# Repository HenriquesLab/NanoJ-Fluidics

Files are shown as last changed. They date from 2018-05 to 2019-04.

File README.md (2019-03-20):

# NanoJ-Fluidics: open-source fluid exchange in microscopy

Note: visit the [**Wiki**][10] or [**Forum**][12] for latest updates.



NanoJ-Fluidics is an open-source device, composed of easily accessible LEGO-parts, electronics and labware. It is designed to automate and simplify fluid exchange experiments in microscopy. Check the paper in Nature Communications: [Automating multimodal microscopy with
NanoJ-Fluidics][11].

## It consists of three parts:
+ [LEGO-based, multiplexable and compact syringe pumps][4]
+ [A simple "hack" to enable liquid exchange on cell culture dishes][5]
+ And a comprehensive [electronic][6] and [software][7] control suite to control the pumps.

This [Wiki][10] provides all the information necessary for researchers to reproduce their own systems and start performing fluidic experiments on their microscopes.

## Developers
NanoJ-Fluidics is developed in a collaboration between the [Henriques][1] and [Leterrier][9] laboratories. 

## Developers
NanoJ-Fluidics is developed in a collaboration between the [Henriques][1] and [Leterrier][9] laboratories, with contributions from the community:
  * [Matthew Meyer][0mgem0] (La Jolla Institute of Allergy & Immunology's Microscopy Core): 3D printed syringe pump body, v-slot adaptor, other parts (see [section](https://github.com/HenriquesLab/NanoJ-Fluidics/wiki/Pumpy-3D-Printing-MMeyer)).
  * [Leo Saunders][MySaundersleo] (University of Colorado Denver): 3D printed syringe pump body (see [section](https://github.com/HenriquesLab/NanoJ-Fluidics/wiki/Pumpy-3D-Printing-LSaunders)).

  [1]: http://www.ucl.ac.uk/lmcb/users/ricardo-henriques
  [2]: http://www.ucl.ac.uk/lmcb/
  [3]: http://www.ucl.ac.uk/
  [4]: https://github.com/HenriquesLab/NanoJ-Fluidics/wiki/Pumpy-Home
  [5]: https://github.com/HenriquesLab/NanoJ-Fluidics/wiki/Labware-Home
  [6]: https://github.com/HenriquesLab/NanoJ-Fluidics/wiki/Electronics-Home
  [7]: https://github.com/HenriquesLab/NanoJ-Fluidics/wiki/GUI-Home
  [8]: https://github.com/HenriquesLab/NanoJ-Fluidics/wiki/Files/PedroPumpsSample.png
  [9]: http://www.neurocytolab.org/
  [10]: https://github.com/HenriquesLab/NanoJ-Fluidics/wiki
  [11]: https://doi.org/10.1038/s41467-019-09231-9
  [12]: https://gitter.im/NanoJ-Fluidics
  [3DPrint]: Pumpy-3D-Printing
  [0mgem0]: https://twitter.com/0mgem0
  [MySaundersleo]: https://twitter.com/MySaundersleo

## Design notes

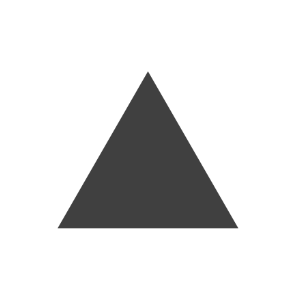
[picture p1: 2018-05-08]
src/nanoj/pumpControl/java/sequentialProtocol/images/up.png

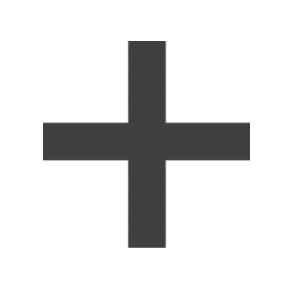
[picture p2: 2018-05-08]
src/nanoj/pumpControl/java/sequentialProtocol/images/duplicate.png

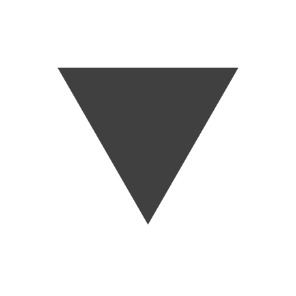
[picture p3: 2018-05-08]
src/nanoj/pumpControl/java/sequentialProtocol/images/down.png

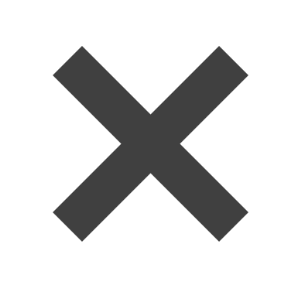
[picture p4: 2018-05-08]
src/nanoj/pumpControl/java/sequentialProtocol/images/expire.png

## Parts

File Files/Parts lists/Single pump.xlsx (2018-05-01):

Name | Picture | Design ID | Quantity
BRICK 2X2 |  | 3003 | 5
BRICK 2X3 |  | 3002 | 1
BRICK 2X4 |  | 3001 | 1
BRICK 2X6 |  | 44237 | 2
BRICK 2X8 |  | 93888 | 1
TECHNIC BRICK 1X6, Ø4,9 |  | 3894 | 5
TECHNIC BRICK 1X10 Ø4.9 |  | 2730 | 4
PLATE 2X3 |  | 3021 | 2
PLATE 2X4 |  | 3020 | 11
PLATE 2X6 |  | 3795 | 3
PLATE 2X16 |  | 4282 | 1
PLATE 8X16 |  | 92438 | 1
BUSH FOR CROSS AXLE |  | 6590 | 7
CROSS AXLE 6M |  | 3706 | 3
CROSS AXLE 8M |  | 3707 | 5
FUNC. MOTOR Ø24X6M |  | 8883-1 | 1 | Not available on Lego Pick a brick
BEAM 1X2 W/CROSS AND HOLE |  | 60483 | 4 | Not available on Lego Pick a brick
CROSS AXLE 12M |  | 3708 | 1 | Not available on Lego Pick a brick
Linear Actuator 10-15 M |  | 61927c01 | 2 | Not available on Lego Pick a brick
GEAR WHEEL T=8, M=1 |  | 3647 | 3 | Not available on Lego Pick a brick
GEAR WHEEL Z24 |  | 3648 | 2 | Not available on Lego Pick a brick
GEAR WHEEL 40T |  | 3649 | 2 | Not available on Lego Pick a brick
 |  |  | 67

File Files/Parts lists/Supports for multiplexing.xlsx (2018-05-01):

Name | Picture | Design ID | Quantity
BRICK 1X2 WITHOUT PIN |  | 3065 | 4
BRICK 2X2 |  | 3003 | 7
TECHNIC BRICK 1X10 Ø4.9 |  | 2730 | 6
 |  |  | 17

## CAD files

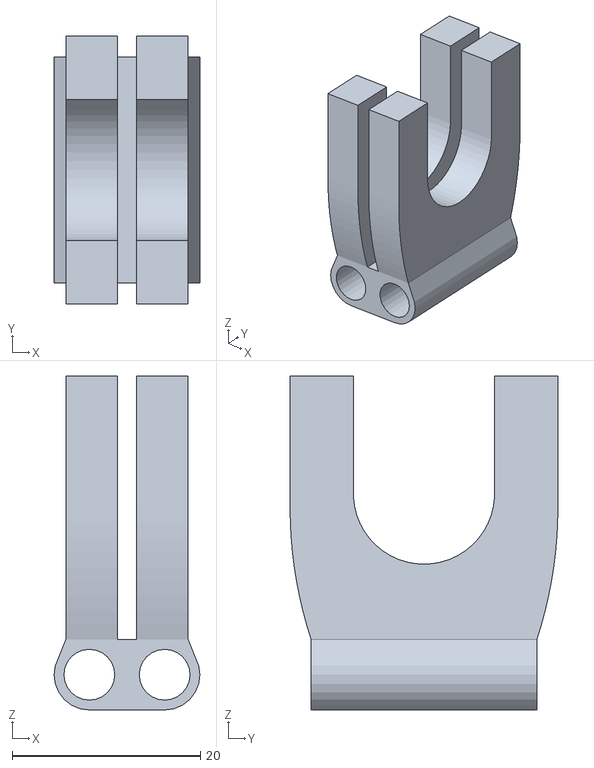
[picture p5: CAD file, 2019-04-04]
Files/3D Printing Parts/MMeyer_Pumpy_BD5ml_2_5.stl
15.5 x 28.5 x 35.5

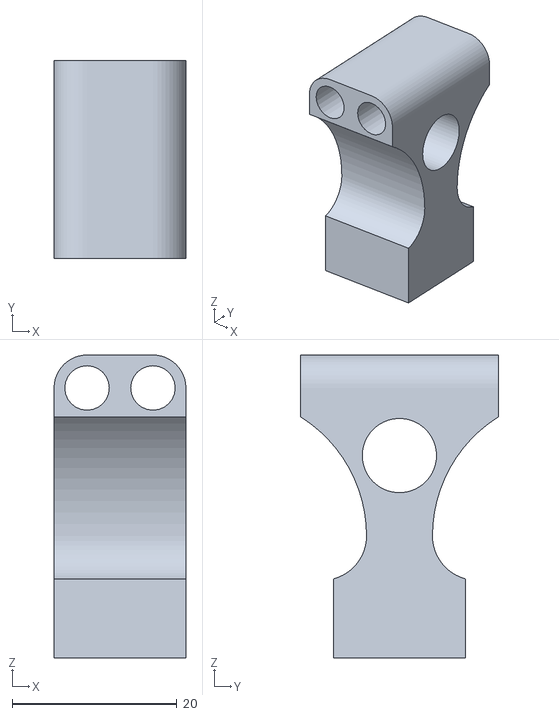
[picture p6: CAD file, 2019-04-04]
Files/3D Printing Parts/MMeyer_Pumpy_LinearActuatorStabilizer_2_5.stl
16.0 x 24.0 x 36.8

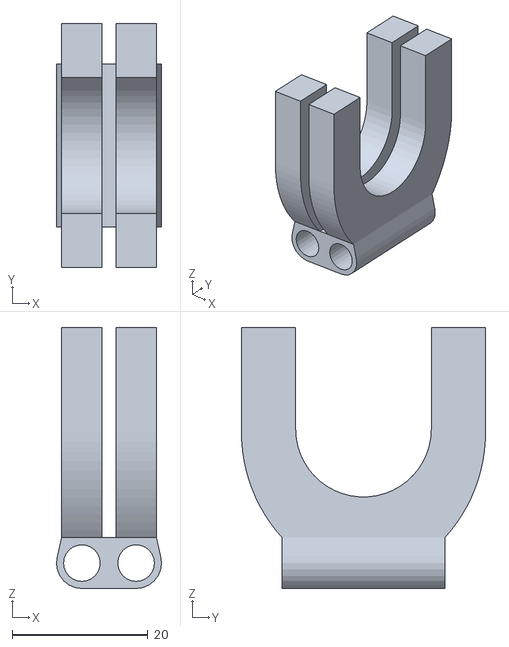
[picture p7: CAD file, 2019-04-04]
Files/3D Printing Parts/MMeyer_Pumpy_BD10ml_2_5.stl
15.5 x 36.0 x 38.5

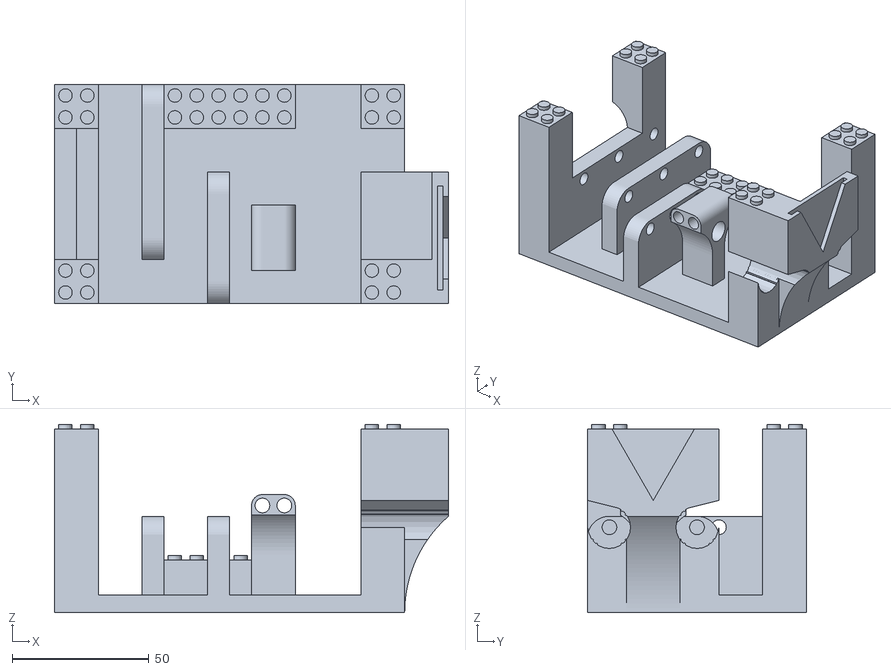
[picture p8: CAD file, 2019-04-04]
Files/3D Printing Parts/MMeyer_SolidPumpy_2_5.stl
144.0 x 80.0 x 68.8

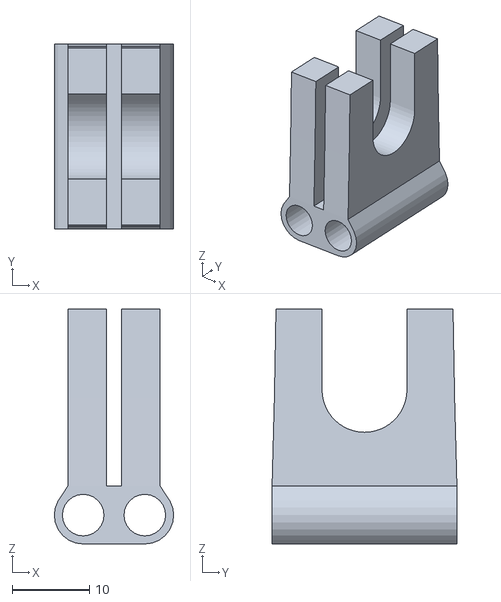
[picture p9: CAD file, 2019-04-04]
Files/3D Printing Parts/MMeyer_Pumpy_BD3ml_2_5.stl
15.5 x 24.0 x 30.5

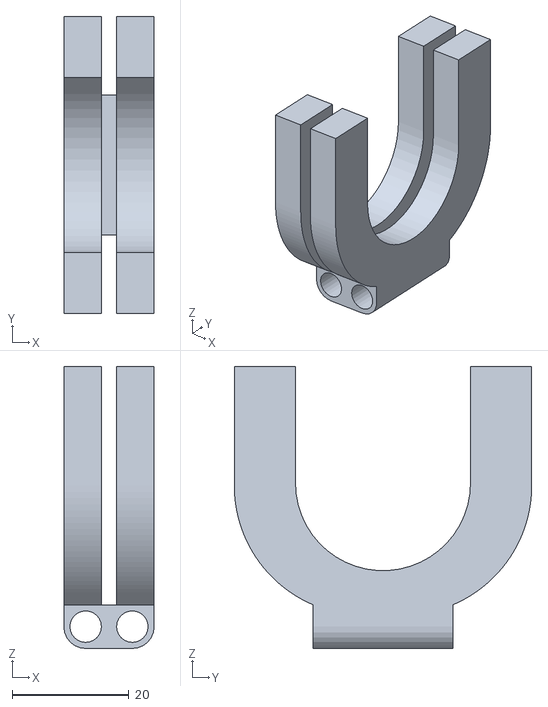
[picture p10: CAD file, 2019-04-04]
Files/3D Printing Parts/MMeyer_Pumpy_BD60ml_2_5.stl
15.5 x 51.0 x 48.3

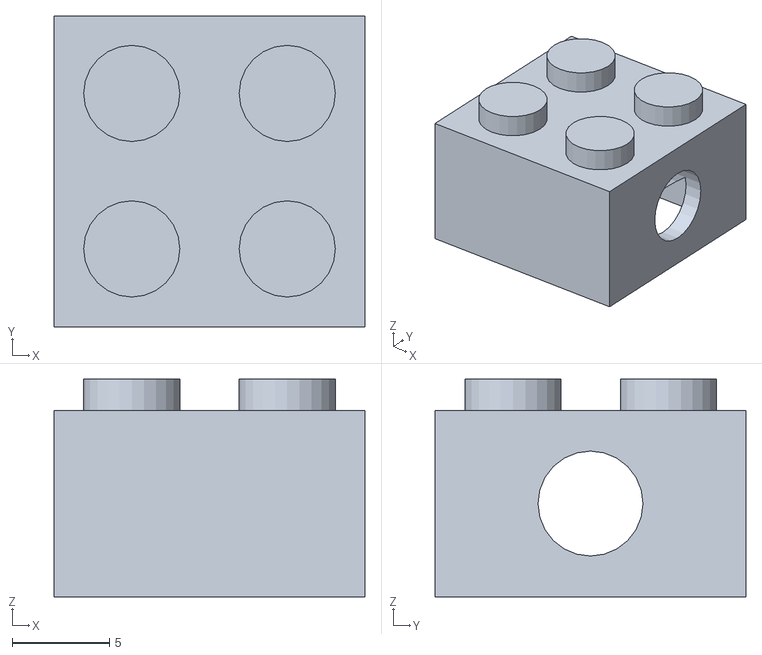
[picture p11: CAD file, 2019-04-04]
Files/3D Printing Parts/MMeyer_Pumpy_PrintingCalibrationBrick_2_5.stl
16.0 x 16.0 x 11.2

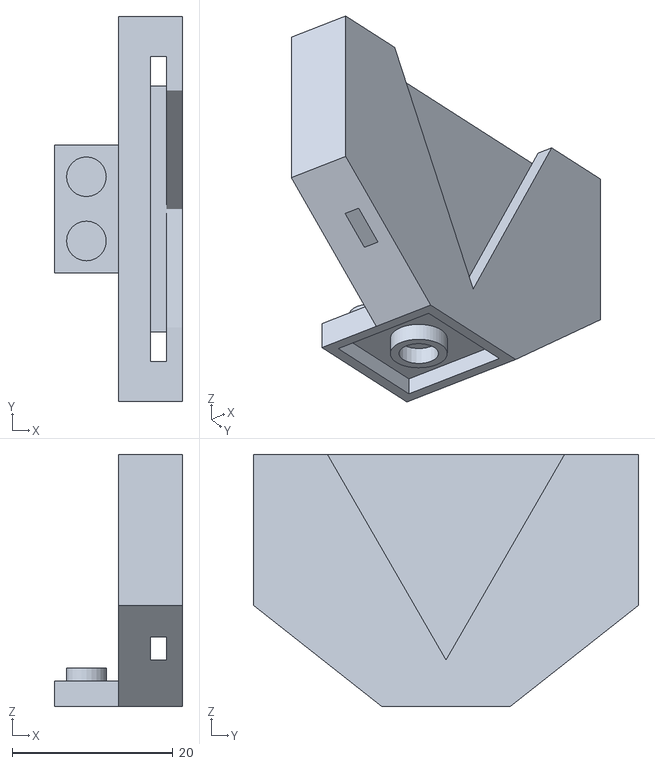
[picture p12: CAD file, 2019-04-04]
Files/3D Printing Parts/MMeyer_Pumpy_VSlot_2_5.stl
16.0 x 48.0 x 31.4

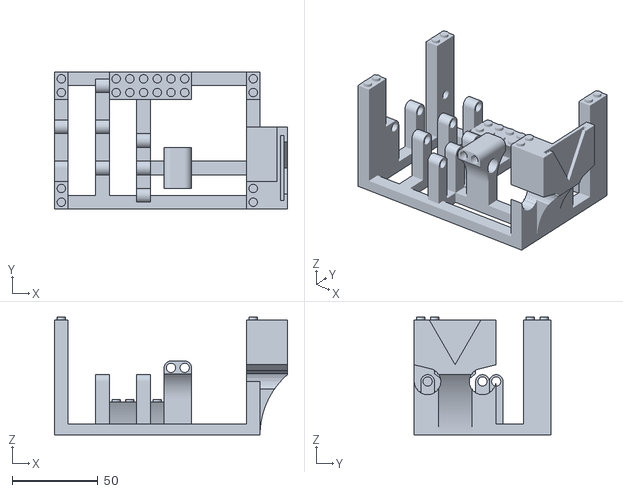
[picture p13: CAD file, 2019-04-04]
Files/3D Printing Parts/MMeyer_SkeletonPumpy_2_5.stl
136.0 x 80.0 x 68.8

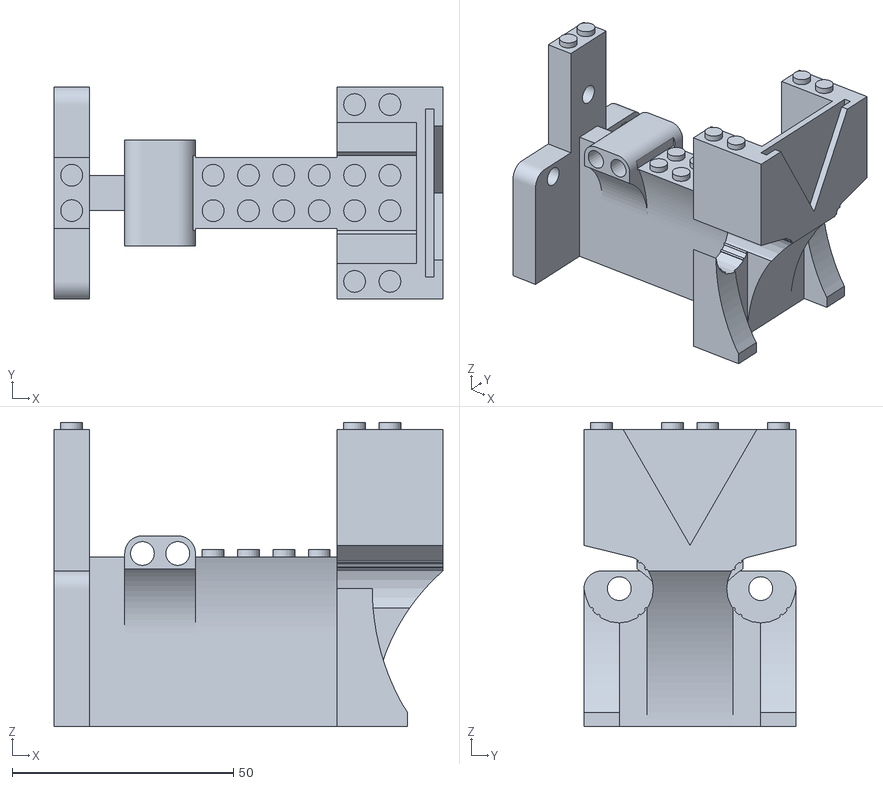
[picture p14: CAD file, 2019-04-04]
Files/3D Printing Parts/MMeyer_PuppyPumpy_2_5.stl
88.0 x 48.0 x 68.8

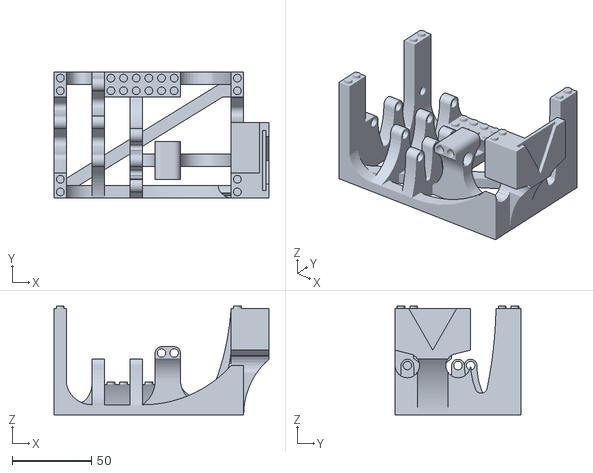
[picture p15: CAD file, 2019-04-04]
Files/3D Printing Parts/MMeyer_DrippyPumpy_2_5.stl
136.0 x 80.0 x 68.8

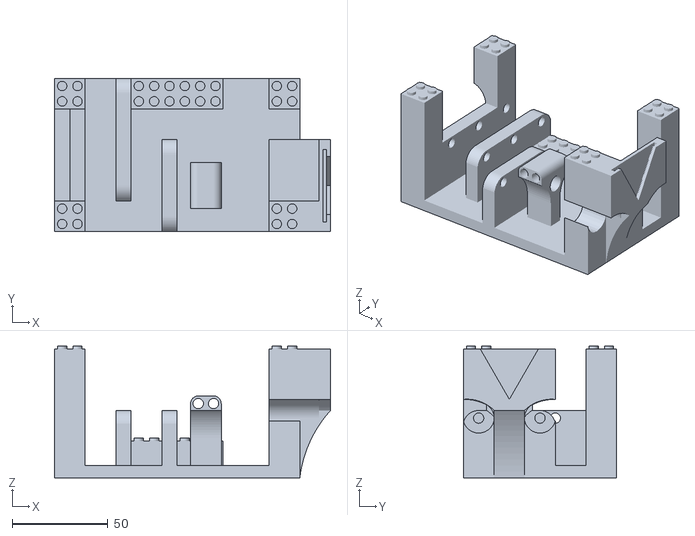
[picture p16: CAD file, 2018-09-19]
Files/3D Printing Parts/MMeyer_Pumpy_2_0.stl
144.0 x 80.0 x 68.8

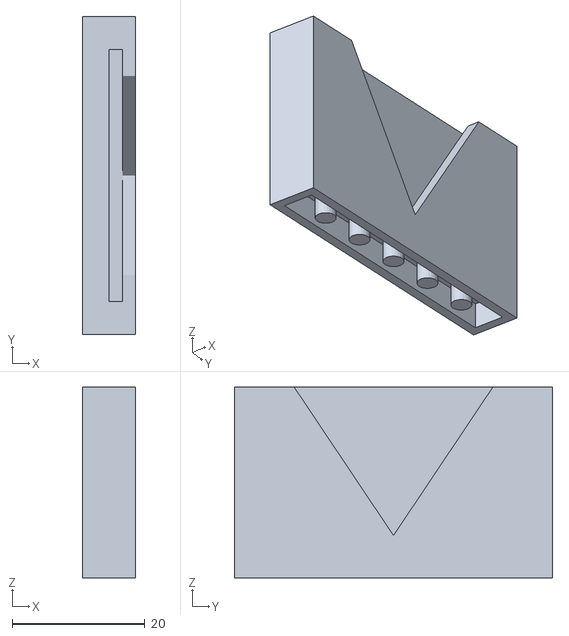
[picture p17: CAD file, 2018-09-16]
Files/3D Printing Parts/MMeyer_VSlotLegoAdaptor_2_0.stl
8.00 x 48.0 x 28.8

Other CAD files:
Files/3D Printing Parts/MMeyer_BD3mlSyringeLinearActuatorAdaptor_2_0.stl
Files/3D Printing Parts/MMeyer_BD5mlSyringeLinearActuatorAdaptor_2_0.stl
Files/3D Printing Parts/MMeyer_BD60mlSyringeLinearActuatorAdaptor_2_0.stl
Files/3D Printing Parts/MMeyer_SkeletonPumpy_2_0.stl
Files/3D Printing Parts/MMeyer_BD10mlSyringeLinearActuatorAdaptor_2_0.stl
Files/3D Printing Parts/LSaunders_ActuatorClamp_1_0.stl
Files/3D Printing Parts/LSaunders_Platform_1_0.stl
Files/3D Printing Parts/LSaunders_SyringeClamp_1_0.stl
Files/3D Printing Parts/MMeyer_Pumpy_1_0.stl
Files/3D Printing Parts/MMeyer_Pumpy_1_1beta.stl
Files/3D Printing Parts/MMeyer_ReplacementForLegoPartsMinosLinearActuator_1_1beta.stl
Files/3D Printing Parts/MMeyer_VSlotLegoAdaptor_1_1beta.stl

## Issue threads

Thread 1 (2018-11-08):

Lack of Lego Pump control in version 1.2.3

MattH688, 2018-11-08:
Hello,

As of version 1.2.3 a commit has been submitted with a complied ".jar" which fails to communicate with the Lego pumps but appears to send commands to the Arduino. I am currently unsure if the issue results from version 1.2.2 as there was no complied ".jar" on that release. So far I have been using the last known working release version 1.2.1.

Many thanks,
MattH688

palmada, 2018-11-09:
Hi @MattH688,

Did you just use the JAR? Or the packaged binaries in https://github.com/HenriquesLab/NanoJ-Fluidics/tree/master/PackagedBinaries?

Kind regards,
Pedro

MattH688, 2018-11-09:
Hi @palmada,

I downloaded the entire project "Manual, source-code and binaries for the NanoJ-Fluidics project". I attempted the ".jar" and have attempted to recompile v1.2.3 this morning. I would like to update my original issue as I have realised direct Lego pump control works* but sequence does not appear to send commands to the correct pump. I have checked and confirmed the messages to the Arduino are correct. I believe it is an issue somewhere with the sequence java files assigning the correct pump index.

Many thanks,
Matthew

*As expected except for failing to stop after the sequence and the hard coded max speed for Lego pumps which I have fixed in my fork. Happy to pull into yours but ideally need sequences fixed first on your master.

palmada, 2018-12-06:
Hi @MattH688 do you still have an issue with the latest release?

MattH688, 2018-12-13:
@palmada Working perfectly now, thanks!

Sorry for the delay, had my viva and other on going work 📃 Happy holidays 👍

Closed 2018-12-13.

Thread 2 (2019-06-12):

Withdraw time acting as pump time

espruston, 2019-06-12:
When designing a sequential protocol the value included for the withdraw time seems to become the amount of time that the pump runs for rather than the time calculated by volume/syringe type. This happens for every pump for every step except for the last step in the protocol, which seems to calculate pump run time as intended. This issue also occurs regardless of whether the "Withdraw between steps?" or "Wd" box is checked next to the step. I'm running on MM 1.4, Windows 10 with an Arduino Uno. Direct pump control works fine.

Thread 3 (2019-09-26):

MM_plugin error

kforti, 2019-09-26:
Hello,
I am getting an error when I try to use NanoJ-Fluidics as a micromanager plugin.

Here are the errors:

`2019-09-26T11:17:20.536925 tid139896359667456 [IFO,App] Plugin command: NanoJ-Fluidics
2019-09-26T11:17:20.537400 tid139896359667456 [IFO,App] Thread 19 (AWT-EventQueue-0) terminated with uncaught exception
2019-09-26T11:17:20.537447 tid139896359667456 [IFO,App] java.lang.NoClassDefFoundError: Could not initialize class nanoj.pumpControl.java.sequentialProtocol.GUI
2019-09-26T11:17:20.537575 tid139896359667456 [IFO,App]   at nanoj.pumpControl.java.sequentialProtocol.MicroManagerPlugin.<init>(MicroManagerPlugin.java:18)
2019-09-26T11:17:20.537586 tid139896359667456 [IFO,App]   at java.base/jdk.internal.reflect.NativeConstructorAccessorImpl.newInstance0(Native Method)
2019-09-26T11:17:20.537598 tid139896359667456 [IFO,App]   at java.base/jdk.internal.reflect.NativeConstructorAccessorImpl.newInstance(NativeConstructorAccessorImpl.java:62)
2019-09-26T11:17:20.537609 tid139896359667456 [IFO,App]   at java.base/jdk.internal.reflect.DelegatingConstructorAccessorImpl.newInstance(DelegatingConstructorAccessorImpl.java:45)
2019-09-26T11:17:20.537620 tid139896359667456 [IFO,App]   at java.base/java.lang.reflect.Constructor.newInstance(Constructor.java:490)
2019-09-26T11:17:20.537632 tid139896359667456 [IFO,App]   at java.base/java.lang.Class.newInstance(Class.java:584)
2019-09-26T11:17:20.537643 tid139896359667456 [IFO,App]   at org.micromanager.pluginmanagement.PluginItem.instantiate(PluginItem.java:89)
2019-09-26T11:17:20.537654 tid139896359667456 [IFO,App]   at org.micromanager.pluginmanagement.PluginManager.displayPlugin(PluginManager.java:110)
2019-09-26T11:17:20.537666 tid139896359667456 [IFO,App]   at org.micromanager.pluginmanagement.PluginManager.access$100(PluginManager.java:22)
2019-09-26T11:17:20.537677 tid139896359667456 [IFO,App]   at org.micromanager.pluginmanagement.PluginManager$2.run(PluginManager.java:64)
2019-09-26T11:17:20.537688 tid139896359667456 [IFO,App]   at org.micromanager.utils.GUIUtils$3.actionPerformed(GUIUtils.java:361)
2019-09-26T11:17:20.537700 tid139896359667456 [IFO,App]   at java.desktop/javax.swing.AbstractButton.fireActionPerformed(AbstractButton.java:1967)
2019-09-26T11:17:20.537711 tid139896359667456 [IFO,App]   at java.desktop/javax.swing.AbstractButton$Handler.actionPerformed(AbstractButton.java:2308)
2019-09-26T11:17:20.537722 tid139896359667456 [IFO,App]   at java.desktop/javax.swing.DefaultButtonModel.fireActionPerformed(DefaultButtonModel.java:405)
2019-09-26T11:17:20.537734 tid139896359667456 [IFO,App]   at java.desktop/javax.swing.DefaultButtonModel.setPressed(DefaultButtonModel.java:262)
2019-09-26T11:17:20.537745 tid139896359667456 [IFO,App]   at java.desktop/javax.swing.AbstractButton.doClick(AbstractButton.java:369)
2019-09-26T11:17:20.537756 tid139896359667456 [IFO,App]   at java.desktop/javax.swing.plaf.basic.BasicMenuItemUI.doClick(BasicMenuItemUI.java:1020)
2019-09-26T11:17:20.537768 tid139896359667456 [IFO,App]   at java.desktop/javax.swing.plaf.basic.BasicMenuItemUI$Handler.mouseReleased(BasicMenuItemUI.java:1064)
2019-09-26T11:17:20.537779 tid139896359667456 [IFO,App]   at java.desktop/java.awt.AWTEventMulticaster.mouseReleased(AWTEventMulticaster.java:297)
2019-09-26T11:17:20.537790 tid139896359667456 [IFO,App]   at java.desktop/java.awt.Component.processMouseEvent(Component.java:6632)
2019-09-26T11:17:20.537802 tid139896359667456 [IFO,App]   at java.desktop/javax.swing.JComponent.processMouseEvent(JComponent.java:3342)
2019-09-26T11:17:20.537813 tid139896359667456 [IFO,App]   at java.desktop/java.awt.Component.processEvent(Component.java:6397)
2019-09-26T11:17:20.537824 tid139896359667456 [IFO,App]   at java.desktop/java.awt.Container.processEvent(Container.java:2263)
2019-09-26T11:17:20.537836 tid139896359667456 [IFO,App]   at java.desktop/java.awt.Component.dispatchEventImpl(Component.java:5008)
2019-09-26T11:17:20.537847 tid139896359667456 [IFO,App]   at java.desktop/java.awt.Container.dispatchEventImpl(Container.java:2321)
2019-09-26T11:17:20.537858 tid139896359667456 [IFO,App]   at java.desktop/java.awt.Component.dispatchEvent(Component.java:4840)
2019-09-26T11:17:20.537870 tid139896359667456 [IFO,App]   at java.desktop/java.awt.LightweightDispatcher.retargetMouseEvent(Container.java:4918)
2019-09-26T11:17:20.537881 tid139896359667456 [IFO,App]   at java.desktop/java.awt.LightweightDispatcher.processMouseEvent(Container.java:4547)
2019-09-26T11:17:20.537892 tid139896359667456 [IFO,App]   at java.desktop/java.awt.LightweightDispatcher.dispatchEvent(Container.java:4488)
2019-09-26T11:17:20.537904 tid139896359667456 [IFO,App]   at java.desktop/java.awt.Container.dispatchEventImpl(Container.java:2307)
2019-09-26T11:17:20.537915 tid139896359667456 [IFO,App]   at java.desktop/java.awt.Window.dispatchEventImpl(Window.java:2772)
2019-09-26T11:17:20.537926 tid139896359667456 [IFO,App]   at java.desktop/java.awt.Component.dispatchEvent(Component.java:4840)
2019-09-26T11:17:20.537938 tid139896359667456 [IFO,App]   at java.desktop/java.awt.EventQueue.dispatchEventImpl(EventQueue.java:772)
2019-09-26T11:17:20.537949 tid139896359667456 [IFO,App]   at java.desktop/java.awt.EventQueue$4.run(EventQueue.java:721)
2019-09-26T11:17:20.537960 tid139896359667456 [IFO,App]   at java.desktop/java.awt.EventQueue$4.run(EventQueue.java:715)
2019-09-26T11:17:20.537972 tid139896359667456 [IFO,App]   at java.base/java.security.AccessController.doPrivileged(Native Method)
2019-09-26T11:17:20.537983 tid139896359667456 [IFO,App]   at java.base/java.security.ProtectionDomain$JavaSecurityAccessImpl.doIntersectionPrivilege(ProtectionDomain.java:85)
2019-09-26T11:17:20.537994 tid139896359667456 [IFO,App]   at java.base/java.security.ProtectionDomain$JavaSecurityAccessImpl.doIntersectionPrivilege(ProtectionDomain.java:95)
2019-09-26T11:17:20.538006 tid139896359667456 [IFO,App]   at java.desktop/java.awt.EventQueue$5.run(EventQueue.java:745)
2019-09-26T11:17:20.538017 tid139896359667456 [IFO,App]   at java.desktop/java.awt.EventQueue$5.run(EventQueue.java:743)
2019-09-26T11:17:20.538029 tid139896359667456 [IFO,App]   at java.base/java.security.AccessController.doPrivileged(Native Method)
2019-09-26T11:17:20.538040 tid139896359667456 [IFO,App]   at java.base/java.security.ProtectionDomain$JavaSecurityAccessImpl.doIntersectionPrivilege(ProtectionDomain.java:85)
2019-09-26T11:17:20.538051 tid139896359667456 [IFO,App]   at java.desktop/java.awt.EventQueue.dispatchEvent(EventQueue.java:742)
2019-09-26T11:17:20.538063 tid139896359667456 [IFO,App]   at java.desktop/java.awt.EventDispatchThread.pumpOneEventForFilters(EventDispatchThread.java:203)
2019-09-26T11:17:20.538074 tid139896359667456 [IFO,App]   at java.desktop/java.awt.EventDispatchThread.pumpEventsForFilter(EventDispatchThread.java:124)
2019-09-26T11:17:20.538085 tid139896359667456 [IFO,App]   at java.desktop/java.awt.EventDispatchThread.pumpEventsForHierarchy(EventDispatchThread.java:113)
2019-09-26T11:17:20.538097 tid139896359667456 [IFO,App]   at java.desktop/java.awt.EventDispatchThread.pumpEvents(EventDispatchThread.java:109)
2019-09-26T11:17:20.538108 tid139896359667456 [IFO,App]   at java.desktop/java.awt.EventDispatchThread.pumpEvents(EventDispatchThread.java:101)
2019-09-26T11:17:20.538119 tid139896359667456 [IFO,App]   at java.desktop/java.awt.EventDispatchThread.run(EventDispatchThread.java:90)
`

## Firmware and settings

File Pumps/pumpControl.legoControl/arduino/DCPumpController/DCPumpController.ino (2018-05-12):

/* 

This is the firmware for an Arduino Uno to drive DC motor pumps through
the Adafruit Motor Shield v2, while under control of our MicroManager
plugins.

© Pedro Almada, UCL, 2015

Commands:
g = get status of all pumps
a = stop all pumps
p = get number of pumps
axy = stop pump xy
sxynnn = for pump xy set speed nnn
rxydttttt - Start pump xy in direction d for ttttt seconds

The commands use this notation:
d = 1 is forward, d = 2 is backwards
x = shield address {1-nShields}
y = motor/pump address {1-nMotorsPerShield}
nnn = speed {000-255}
ttttt = duration {00001-99999}

Our testing with 1 ml syringe tells us the speed will correspond to:
255 - 2.3 microliters/second

*/

//// Imports
#include <EEPROM.h>
// Adafruit Motor Shield libraries
#include <Wire.h>
#include <Adafruit_MotorShield.h>

//// Settings

// Number of shields (MAX: 9)
const int nShields = 4;
// Number of DC motors per shield (MAX on Adafruit Motor Shield v2: 4)
const int nMotorsPerShield = 4;
// Character which signals end of message from PC
char endMessage = '.';

// Misc. initializations
byte currentShield;
byte currentMotor;
int eeAddress = 0;
const int maxMessageLength = 9;
unsigned long startTime = 0;
unsigned long elapsedTime = 0;
unsigned long targetTime = 0;
boolean timeCounter = false;
Adafruit_MotorShield afms[nShields];
Adafruit_DCMotor *motor[nShields][nMotorsPerShield];

// The Arduino should keep track of what the motors have been told to do. 
// We can address each motor's status by accessing the values on motorStatus
// Format is: [shield][motor][speed/state]
// Speed can vary from 0 to 255
// States are: 0 - stop; 1 - forward; 2 - backward.
int motorStatus[nShields][nMotorsPerShield][2] = {{}};

void setup() {
  // Start serial communication and set baud-rate
  Serial.begin(57600);
  Serial.println("Connected!");

  // We now create a Motor Shield object for each shield. Their address 
  // (96-128) is set by soldering a few jumpers.
  // see: https://learn.adafruit.com/adafruit-motor-shield-v2-for-arduino/stacking-shields
  // Note here I'm using decimal values for the address which is simpler
  // but their tutorial uses hex.
  
  unsigned char address = 96;

  // Create array of shield objects
  
  for (int i=0; i<nShields; i++) {
    afms[i] = Adafruit_MotorShield(address);
    address = ++address;
    // Initialize shield objects with the default frequency 1.6KHz
    afms[i].begin();
  }

  // For each shield we then get each of the their motors.
  EEPROM.get(eeAddress, motorStatus);
  for (int i=0; i<nShields; i++) {
    for (int j=0; j<nMotorsPerShield; j++) {
      motor[i][j] = afms[i].getMotor(j+1);
      motor[i][j]->setSpeed(motorStatus[i][j][0]);
    }
  }
}

void loop() {
  char incoming[maxMessageLength];
  
  // If a pump has been started, we stop all pumps after a targetTime amount of time
  if (timeCounter == true) {
    elapsedTime = millis() - startTime;
    if (elapsedTime >= targetTime) {
      for (int i=0; i < nShields; i++) {
           for (int j=0; j < nMotorsPerShield; j++) {
             motorStatus[i][j][1] = 0;
             EEPROM.put(eeAddress, motorStatus);
             motor[i][j]->run(RELEASE);
           }
       }
       elapsedTime = 0;
       targetTime = 0;
       timeCounter = false;
    }
  }
  // If there is a message from the serial port
  if (Serial.available() > 0) {
     
     // Read buffer until end character is reached or maxMessageLength characters are read.
     int lengthOfMessage = Serial.readBytesUntil(endMessage,incoming,maxMessageLength);
     
     // The incoming message will be char array and we're using element 0
     // to determine what is the action to be performed by the pump.
     // The next characters will determine optional parameters such as
     // what pump to start, what speed to set, etc...
     
     // If incoming message is:
     // g = get status of all pumps
     if (incoming[0] == 'g') {
       for (int i=0; i < nShields; i++) {
         for (int j=0; j < nMotorsPerShield; j++) {
           Serial.print("S");
           Serial.print(i + 1);
           Serial.print("M");
           Serial.print(j + 1);
           Serial.print(":");
           Serial.print(motorStatus[i][j][0]);
           Serial.print(",");
           Serial.print(motorStatus[i][j][1]);
           Serial.print(";");
         }
       }
     Serial.println();
     }
     
     // a = stop all pumps
     else if (incoming[0] == 'a' && lengthOfMessage == 1) {
       for (int i=0; i < nShields; i++) {
         for (int j=0; j < nMotorsPerShield; j++) {
           motorStatus[i][j][0] = 255;
           motorStatus[i][j][1] = 0;
           EEPROM.put(eeAddress, motorStatus);
           motor[i][j]->run(RELEASE);
         }
       }
       elapsedTime = 0;
       timeCounter = false;
       Serial.print("Stopped all pumps!");
       Serial.println();
     }
     
     // axy = stop pump xy
     else if (incoming[0] == 'a' && lengthOfMessage != 1) {
       currentShield = incoming[1] - '0' - 1;
       currentMotor  = incoming[2] - '0' - 1;
       motorStatus[currentShield][currentMotor][1] = 0;
       EEPROM.put(eeAddress, motorStatus);
       motor[currentShield][currentMotor]->run(RELEASE);

       elapsedTime = 0;
       timeCounter = false;
       Serial.print("Stopped pump: ");
       Serial.print(incoming[1]);
       Serial.print(",");
       Serial.print(incoming[2]);
       Serial.print("!");
       Serial.println();
     }
     
     //p = get number of pumps
     else if (incoming[0] == 'p') {
      String s = String(nShields, DEC);
      String m = String(nMotorsPerShield, DEC);
      String result = String(s + "." + m);
      Serial.print(result);
      Serial.println();
     }
     
     // sxynnn = for pump xy set speed nnn
     else if (incoming[0] == 's') {
       currentShield = incoming[1] - '0' - 1;
       currentMotor  = incoming[2] - '0' - 1;
       byte a = incoming[3] - '0';
       byte b = incoming[4] - '0';
       byte c = incoming[5] - '0';
       byte currentSpeed = (a*100)+(b*10)+c;
       
       motorStatus[currentShield][currentMotor][0] = currentSpeed;
       EEPROM.put(eeAddress, motorStatus);
       motor[currentShield][currentMotor]->setSpeed(currentSpeed);
       
       Serial.print("Set speed of pump: ");
       Serial.print(incoming[1]);
       Serial.print(",");
       Serial.print(incoming[2]);
       Serial.print(" to ");
       Serial.print(currentSpeed);
       Serial.println();
     }
     
     // rxydttttt - Start pump xy in direction d for ttttt seconds
     // d = 1 is forward, d = 2 is backwards
     else if (incoming[0] == 'r' && lengthOfMessage == maxMessageLength) {
       char targetTimeInput[5] = {incoming[4],incoming[5],incoming[6],incoming[7],incoming[8]};
       targetTime = atol(targetTimeInput)*1000;
       currentShield = incoming[1] - '0' - 1;
       currentMotor  = incoming[2] - '0' - 1;
       motorStatus[currentShield][currentMotor][1] = incoming[3] - '0';
       EEPROM.put(eeAddress, motorStatus);
       
       if (incoming[3] == '1') {
         motor[currentShield][currentMotor]->run(FORWARD);
         startTime = millis();
         elapsedTime = 0;
         timeCounter = true;
         Serial.print("Started pump: ");
         Serial.print(incoming[1]);
         Serial.print(",");
         Serial.print(incoming[2]);
         Serial.print(" in the forward direction.");
         Serial.println();
       }
       else if (incoming[3] == '2') {
         startTime = millis();
         elapsedTime = 0;
         timeCounter = true;
         motor[currentShield][currentMotor]->run(BACKWARD);
         Serial.print("Started pump: ");
         Serial.print(incoming[1]);
         Serial.print(",");
         Serial.print(incoming[2]);
         Serial.print(" in the backward direction.");
         Serial.println();
       };
     }
     
     else {
        Serial.println();
     }
  }
}

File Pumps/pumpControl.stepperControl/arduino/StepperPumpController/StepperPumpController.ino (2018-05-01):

/* 

This is the firmware for an Arduino Uno to drive DC motor pumps through
the Adafruit Motor Shield v2, while under control of our MicroManager
plugins.

© Pedro Almada, UCL, 2015

Commands:
g = get status
a = stop pump
snnn = for pump xy set speed nnn
rdtttttttt - Start pump xy in direction d for ttttttt steps

The commands use this notation:
d = 1 is forward, d = 2 is backwards
nnn = speed {000-maximumSpeed}
ttttttt = steps {0000001-9999999}



*/

//// Imports
#include <EEPROM.h>
// Adafruit Motor Shield libraries
#include <Wire.h>
#include <Adafruit_MotorShield.h>
#include <AccelStepper.h>
#include "utility/Adafruit_PWMServoDriver.h"


// How many steps can the motor take per full revolution?
const uint16_t resolution = 3200;
const uint16_t maximumSpeed = 400;


// Character which signals end of message from PC
char endMessage = '.';

// Misc. initializations
int eeAddress = 0;
int motorStatus = 0;
const uint32_t acceleration = resolution*resolution;
const int maxMessageLength = 9;
Adafruit_MotorShield shield = Adafruit_MotorShield();
Adafruit_StepperMotor *motor = shield.getStepper(resolution, 1);

void forward() {  
  motor->onestep(FORWARD, MICROSTEP);
}
void backward() {  
  motor->onestep(BACKWARD, MICROSTEP);
}

AccelStepper stepper(forward, backward);

void setup() {
  // Start serial communication and set baud-rate
  Serial.begin(57600);
  Serial.println("Connected!");

  shield.begin();

  stepper.setMaxSpeed(resolution);
  stepper.setAcceleration(acceleration);
  
  motor->release();
}

void loop() {
  stepper.run();
  char incoming[maxMessageLength];

  // If there is a message from the serial port
  if (Serial.available() > 0) {
     stepper.run();
     
     // Read buffer until end character is reached or maxMessageLength characters are read.
     int lengthOfMessage = Serial.readBytesUntil(endMessage,incoming,maxMessageLength);
     
     stepper.run();
     
     // The incoming message will be char array and we're using element 0
     // to determine what is the action to be performed by the pump.
     // The next characters will determine optional parameters such as
     // what pump to start, what speed to set, etc...

    // get status of pump
    if (incoming[0] == 'g') {
     Serial.print(motorStatus);
     Serial.println();
     }
     
     // a = stop pump
     else if (incoming[0] == 'a') {
       stepper.stop();
       //stepper.moveTo(stepper.currentPosition());
       motorStatus = 0;
       EEPROM.put(eeAddress, motorStatus);
       Serial.print("Stopped pump!");
       Serial.println();
       
     }
     
     
     // snnn = set speed nnn
     else if (incoming[0] == 's' & lengthOfMessage == 4) {
       char s[7];
        for (int i = 1; i < 4; i++) {
          s[i-1] = incoming[i];
        }
       uint16_t currentSpeed = atol(s);

       if (currentSpeed > maximumSpeed) {
        currentSpeed = maximumSpeed;
       }
       
       stepper.setMaxSpeed(currentSpeed);
       stepper.setAcceleration(currentSpeed*currentSpeed);
       
       Serial.print("Set speed of pump to: ");
       Serial.print(currentSpeed);
       Serial.println();
     }


     
     // rdttttttt - Start pump in direction d for 9999999 steps
     // d = 1 is forward, d = 2 is backwards
     else if (incoming[0] == 'r') {
        char ta[7];
        for (int i = 2; i < 9; i++) {
          ta[i-2] = incoming[i];
        }
        uint32_t target = atol(ta);
       
       if (incoming[1] == '1') {
         Serial.print("Started pump in the forward direction for ");
         Serial.print(target);
         Serial.print(" steps.");
         Serial.println();
         stepper.move(target);
         stepper.run();
         motorStatus = 1;
         EEPROM.put(eeAddress, motorStatus);
       }
       
       else if (incoming[1] == '2') {
         Serial.print("Started pump in the backward direction for ");
         Serial.print(target);
         Serial.print(" steps.");
         Serial.println();
         stepper.move(-target);
         motorStatus = 2;
         EEPROM.put(eeAddress, motorStatus);
       };
     }
     
     else {
       stepper.run();
        Serial.print("Yes?");
        Serial.println();
     }
  }  

  
}

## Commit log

2018-05-01 moves files to Files folder
    [Single pump.xlsx, Support plates.xlsx, Supports for multiplexing.xlsx]
2018-05-01 adding pump controller and GUI
2018-05-07 Image of the IntelliJ build buttons for the wiki
2018-05-08 Adding peristaltic option to the syringes
2018-05-12 Fixing spurious library that prevented compilation of firmware
    [DCPumpController.ino]
2018-05-12 Fixing peristaltic pump flow-rate
2018-08-06 Fixing appearance of Stop Pump button on sequential labelling tab
2018-08-09 Testing new Pump Structure
2018-08-11 New structure fully functional
    Only pump status needs to be updated
2018-08-11 Pump status now outputs correctly
    Only dummy follows new pattern.
2018-08-11 Updating remaining pumps
2018-08-11 Added calibration table
2018-08-11 Pump Calibration table can now change calibration of pumps
2018-08-11 Calibration table now remembers values between sessions
2018-08-11 Reset Calibration Button now works
2018-08-11 Fixing bug where calibration wasn't reflected on the pump object
2018-08-12 Load calibration button works as intended
    But now flow-rate sliders are broken.
2018-08-12 Calibration tab's dimensions are now handled by the GUI properly
2018-08-12 Fixed flow-rate slider dimensions
2018-08-12 Fixing issue with rate slider not updating with pump selection
2018-08-12 Added pumping time estimate
2018-08-12 Generified stop button
2018-08-12 Adding stop button sanity check
2018-08-12 Added GUI inputs allowing the pumps to be started by time, not volume
2018-08-12 Fixing bug with calibration procedure
2018-08-18 Making disconnect button work based on the port on the Dropdown list.
2018-08-24 Adding 3D print body by MMeyers
    [MMeyers_Pumpy_1_0.stl]
2018-08-28 adding new 3D part design
    [MMeyers_Pumpy_1_1.stl, MMeyers_Pumpy_1_1beta.stl, MMeyers_ReplacementForLegoPartsMinosLinearActuator_1_1beta.stl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]
2018-08-28 fix name on 3D printed files
    [LSaunders_ActuatorClamp_1_0.stl, LSaunders_Platform_1_0.stl, LSaunders_SyringeClamp_1_0.stl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]
2018-10-07 Exposing the current step through the GUI.
2018-10-07 Allowing scripts to stop pumps.
2018-10-10 Moving Syringe definition to an enum to allow for easy discrimination of what is a peristaltic pump or not.
2018-10-10 Fixing logic of previous commit that assumed peristaltic pumps would only be used for withdrawal.
